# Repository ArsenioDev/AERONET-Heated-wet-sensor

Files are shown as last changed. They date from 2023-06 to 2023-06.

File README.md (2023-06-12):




# AERONET-Heated-wet-sensor

## Heated Wet Sensor for the NASA AERONET program

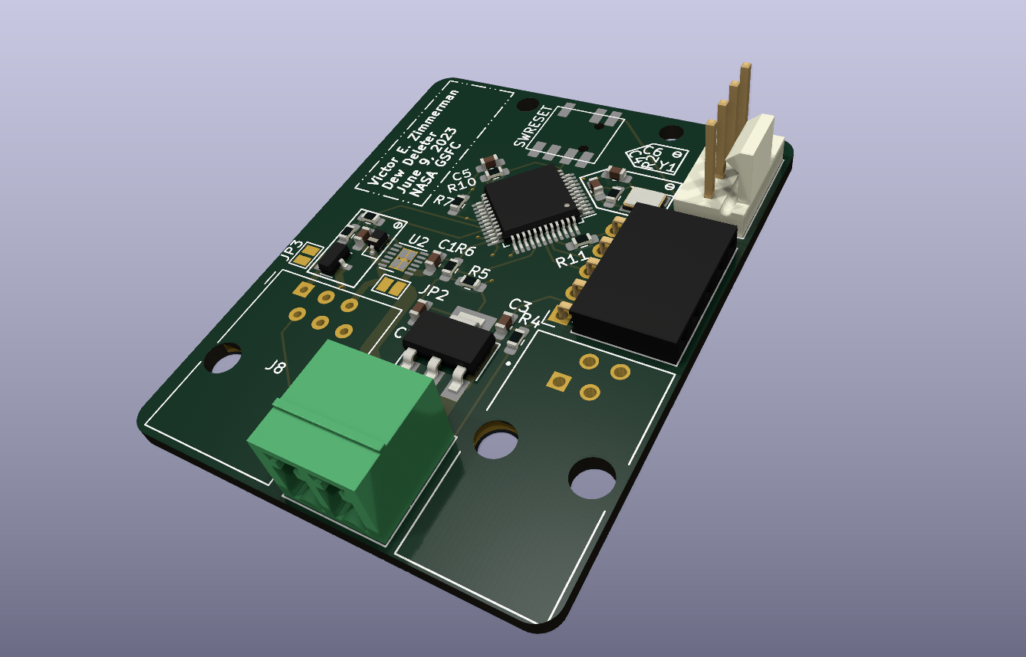
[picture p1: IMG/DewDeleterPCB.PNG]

Designed as part of USNA-to-NASA internship by Victor Zimmerman. 

### Description

A PCB designed to cure NASA AERONET robots suffering from dew induced crepuscular narcolepsy (instruments remaining in standby due to dew on wet sensor). The PCB is connected to temperature sensors, CIMEL control box and a heated wet sensor, in order to determine if the wet sensor is at risk of dew condensation. If so, turns on heater to prevent dew condensation. Determines dew risk by calculating dew point at BME280(atmospheric DP) and compares it to dew point calculated by temperature sensor underneath heated wet sensor(Sensor DP). Heats wet sensor until sensor DP is higher than atmospheric DP. Formula used to calculate dew point: 

𝐷𝑃=𝑇−(100 −𝐻)/5

Is mostly a "plug-and-play" design; does not need any programming or input from operator beyond initial code load. Runs on 12V and minimum 1.5A AC power supply (1.2A of which is for the heater, I_Lim set by load driver).

#### Initial code load prerequisites/software dependencies
* Arduino IDE with [STM32Duino](https://github.com/stm32duino/Arduino_Core_STM32) BSP core added
* Include libraries: [BolderFlight BME280](https://github.com/bolderflight/bme280), [OneWire](https://github.com/PaulStoffregen/OneWire), and [DallasTemperature](https://github.com/milesburton/Arduino-Temperature-Control-Library)
* SWD (Serial Wire Debug) upload mechanism from list of uploads. 
* Core selected **Generic STM32F103C6**

### Progress
- [x] Attempted to use RX8130
- [x] failed to use RX8130 :(
- [x] Succesfully pivoted to DS3121
- [x] realized RTC was unneccesary 
- [x] finished code
- [x] finished spahgetti point to point (with italian falg colored wires)
- [ ] ~~failed test in temperature chamber~~
- [x] ~~give up creating dew condensation after a PHD told us it would not work~~
- [x] Meanwhile, forced dew condensation in temperature chamber
- [x] Defined schematic of PCB with teensy stand in
- [x] replaced teensy with STM32F103
- [x] Finished schematic
- [x] routed PCB
- [x] Fine Tuned
- [x] Swagged out silkscreen
- [x] issued production order
- [x] finished progress list
- [ ] finished README and documentat...zzz

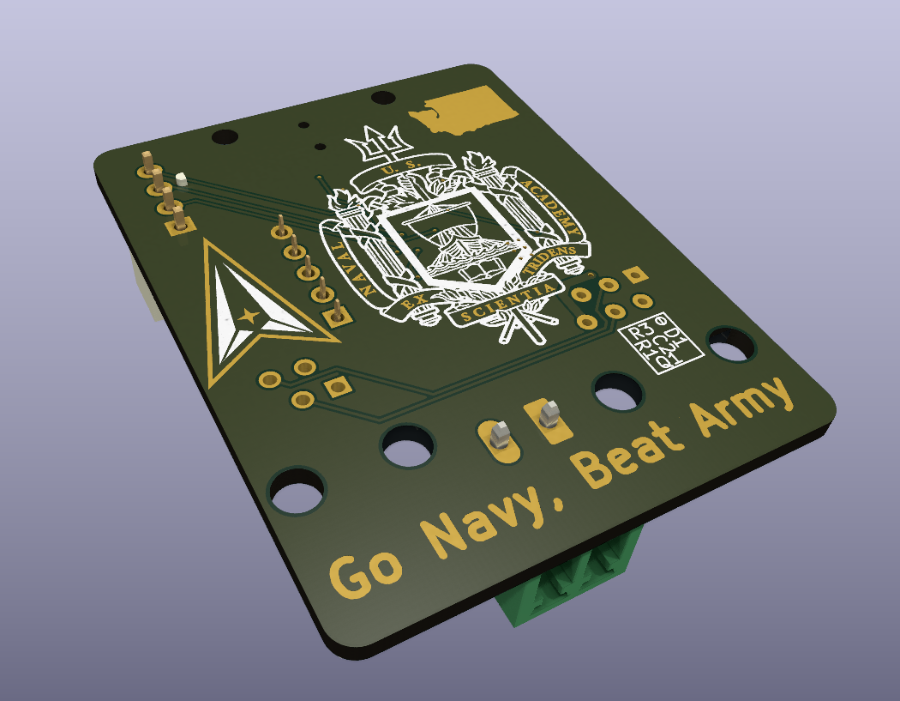
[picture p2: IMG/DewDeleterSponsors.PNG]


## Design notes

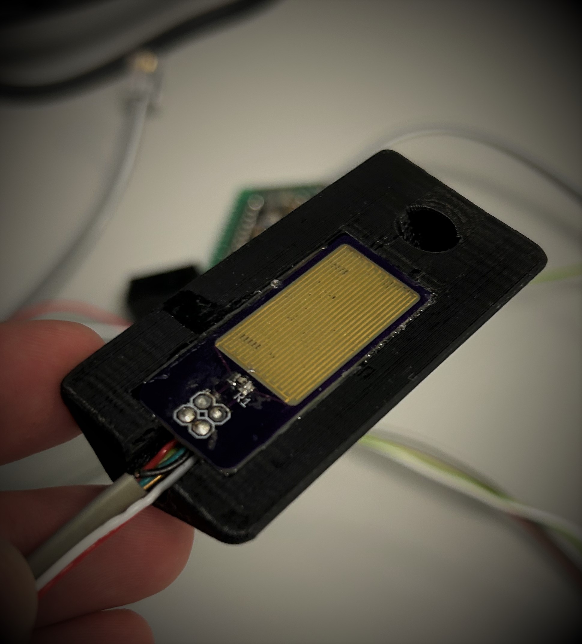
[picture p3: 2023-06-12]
IMG/IMG-4535_focused.jpg

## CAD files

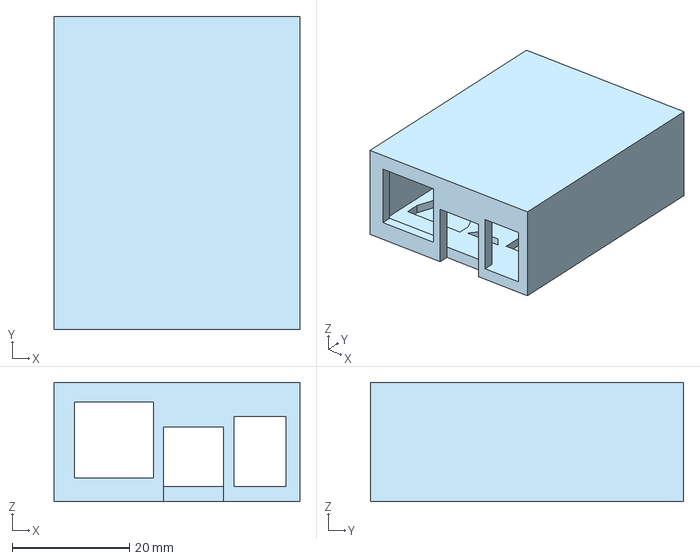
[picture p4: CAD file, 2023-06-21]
Hardware/Mechanical/Control unit holder.step
41.9 x 53.3 x 20.3 mm

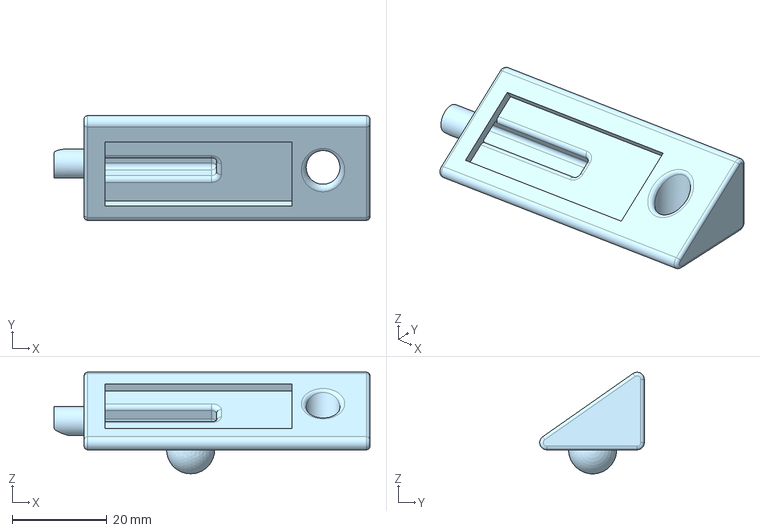
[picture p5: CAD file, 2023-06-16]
Hardware/Mechanical/Heated wet sensor holder.step
66.7 x 22.1 x 21.4 mm

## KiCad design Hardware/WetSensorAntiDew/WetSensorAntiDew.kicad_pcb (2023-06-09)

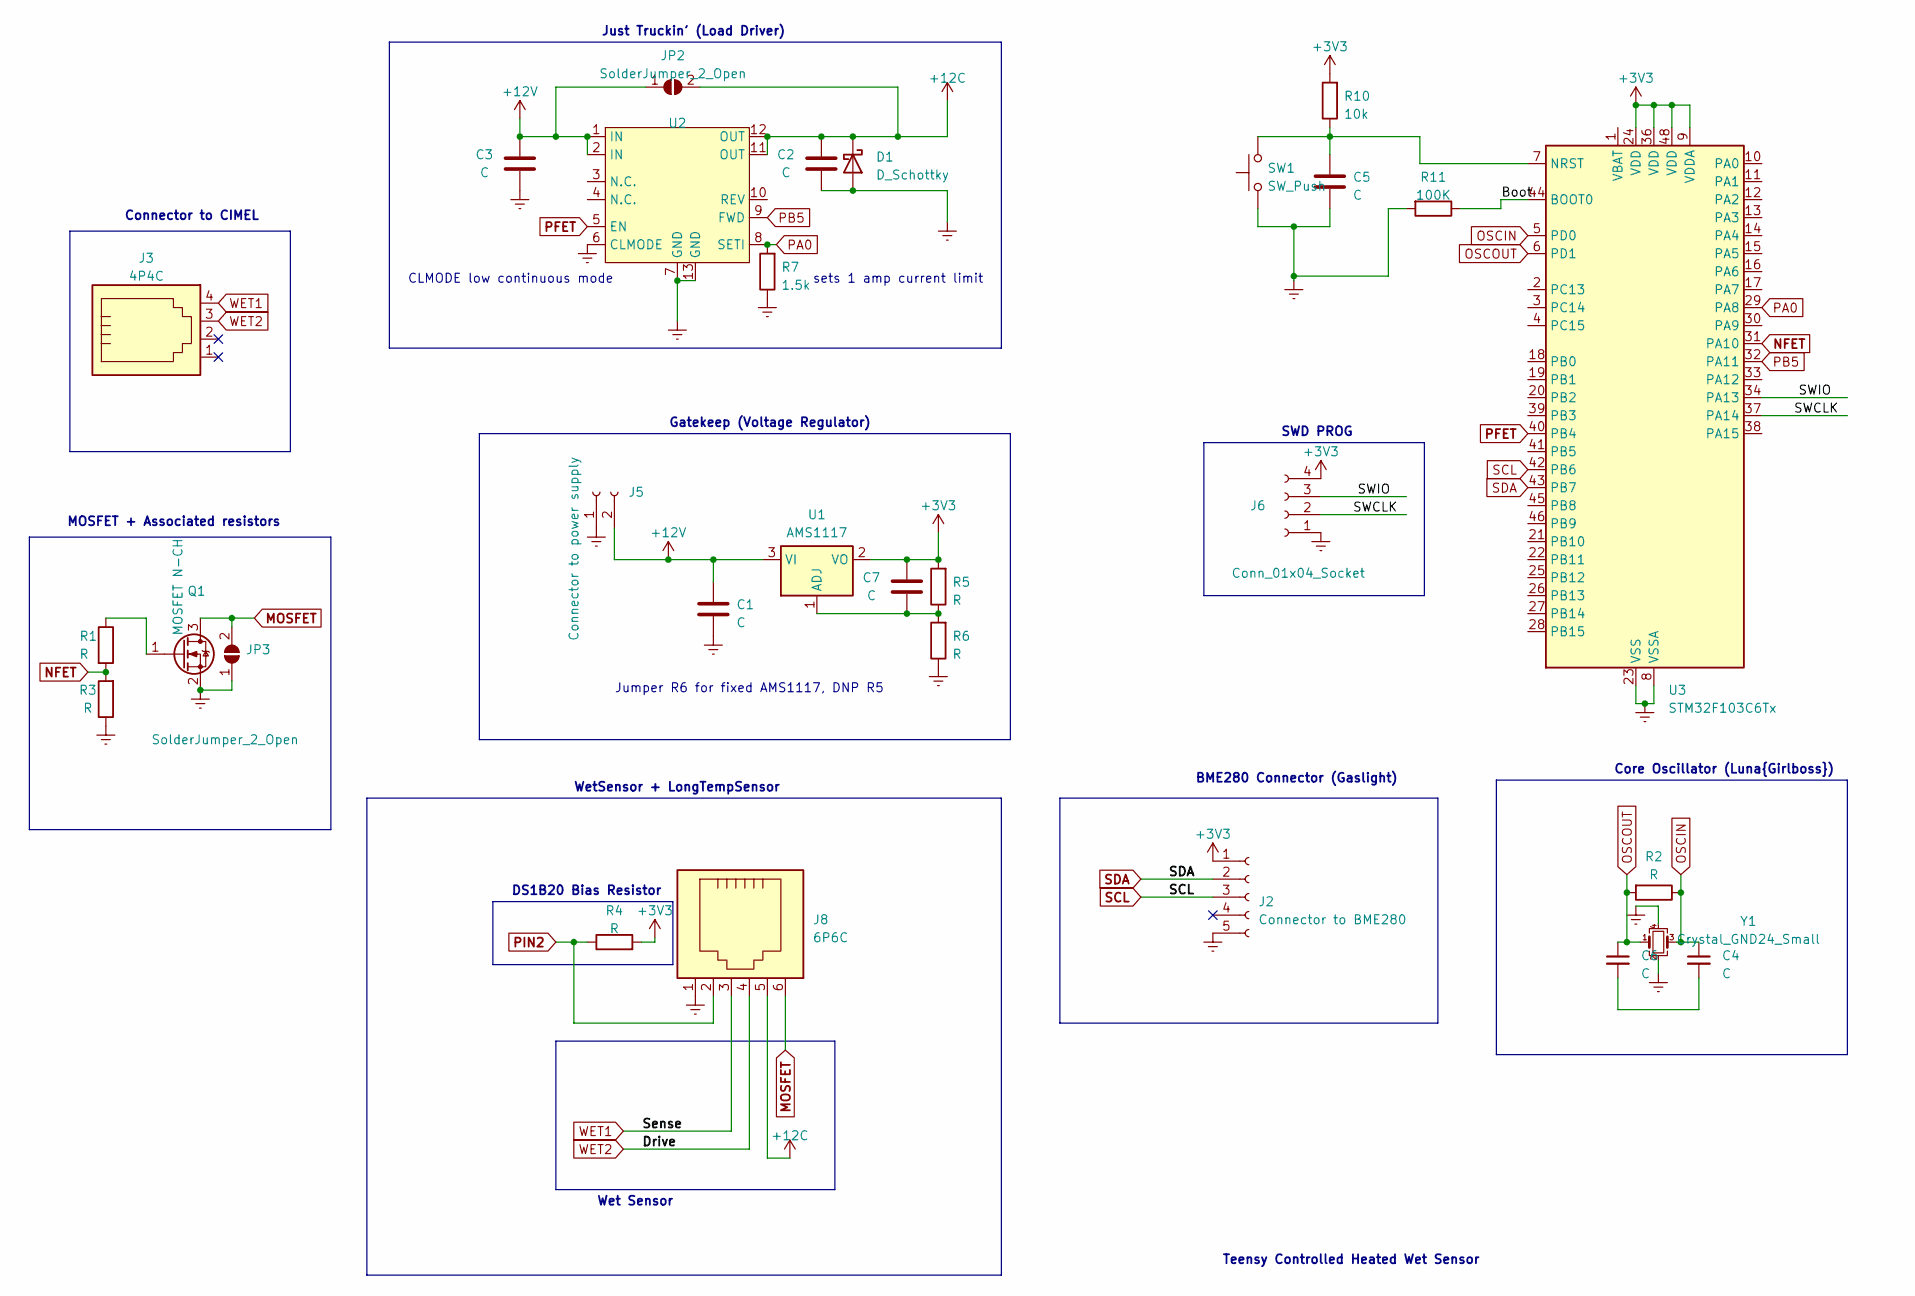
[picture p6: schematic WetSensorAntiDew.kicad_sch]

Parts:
C1, C2, C3, C4, C5, C6, C7: C; C_0603_1608Metric_Pad1.08x0.95mm_HandSolder
D1: D_Schottky; D_SOD-323
J2: Connector to BME280; PinSocket_1x05_P2.54mm_Horizontal
J3: 4P4C; BEL_SS-6444-NF
J5: Connector to power supply; PhoenixContact_MC_1,5_2-G-3.81_1x02_P3.81mm_Horizontal
J6: Conn_01x04_Socket; FanPinHeader_1x04_P2.54mm_Vertical
J8: 6P6C; RJ12_Amphenol_54601
JP2, JP3: SolderJumper_2_Open; SolderJumper-2_P1.3mm_Open_Pad1.0x1.5mm
Q1: MOSFET N-CH; SOT-23
R1, R2, R3, R4, R5, R6: R; R_0603_1608Metric_Pad0.98x0.95mm_HandSolder
R7: 1.5k; R_0603_1608Metric_Pad0.98x0.95mm_HandSolder
R10: 10k; R_0603_1608Metric_Pad0.98x0.95mm_HandSolder
R11: 100K; R_0603_1608Metric_Pad0.98x0.95mm_HandSolder
SW1: SW_Push; 228EJVAYFR
U1: AMS1117; SOT-223-3_TabPin2
U2: DFN-12-1EP_3x3mm_P0.5mm_EP1.6x2.5mm_ThermalVias
U3: STM32F103C6Tx; LQFP-48_7x7mm_P0.5mm
Y1: Crystal_GND24_Small; Crystal_SMD_3225-4Pin_3.2x2.5mm

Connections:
+3V3: C7.1, J2.1, J6.4, R4.2, R5.2, R10.2, U1.2 (VO), U3.9 (VDDA), U3.24 (VDD), U3.36 (VDD), U3.48 (VDD)
+12C: C2.1, D1.1 (K), J8.5, JP2.2 (B), U2.11 (OUT), U2.12 (OUT)
+12V: C1.1, C3.1, J5.2, JP2.1 (A), U1.3 (VI), U2.1 (IN), U2.2 (IN)
/Boot: R11.1, U3.44 (BOOT0)
/SWCLK: J6.2, U3.37 (PA14)
/SWIO: J6.3, U3.34 (PA13)
Earth: C1.2, C2.2, C3.2, C5.2, D1.2 (A), J2.5, J5.1, J6.1, J8.1, JP3.1 (A), Q1.2 (S), R3.1, R6.1, R7.1, R11.2, SW1.1, U2.6 (CLMODE), U2.7 (GND), U2.13 (GND), U3.8 (VSSA), U3.23 (VSS), U3.35 (VSS), U3.47 (VSS), Y1.2, Y1.4; also elsewhere on the board
MOSFET: J8.6, JP3.2 (B), Q1.3 (D)
NFET: R1.2, R3.2, U3.31 (PA10)
unnamed: C4.2, C6.2
unnamed: Q1.1 (G), R1.1
unnamed: C7.2, R5.1, R6.2, U1.1 (ADJ)
unnamed 12: C5.1, R10.1, SW1.2, U3.7 (NRST); also elsewhere on the board
OSCIN: C4.1, R2.1, U3.5 (PD0), Y1.3
OSCOUT: C6.1, R2.2, U3.6 (PD1), Y1.1
PA0: R7.2, U2.8 (SETI), U3.29 (PA8)
PB5: U2.9 (FWD), U3.32 (PA11)
PFET: U2.5 (EN), U3.40 (PB4)
PIN2: J8.2, R4.1
SCL: J2.3, U3.42 (PB6)
SDA: J2.2, U3.43 (PB7)
WET1: J3.4, J8.3
WET2: J3.3, J8.4

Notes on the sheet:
DS1B20 Bias Resistor
CLMODE low continuous mode
Wet Sensor
MOSFET + Associated resistors
BME280 Connector (Gaslight)
Jumper R6 for fixed AMS1117, DNP R5
Connector to CIMEL
WetSensor + LongTempSensor
Teensy Controlled Heated Wet Sensor
sets 1 amp current limit
Just Truckin' (Load Driver)
Core Oscillator (Luna{Girlboss})
Gatekeep (Voltage Regulator)
SWD PROG

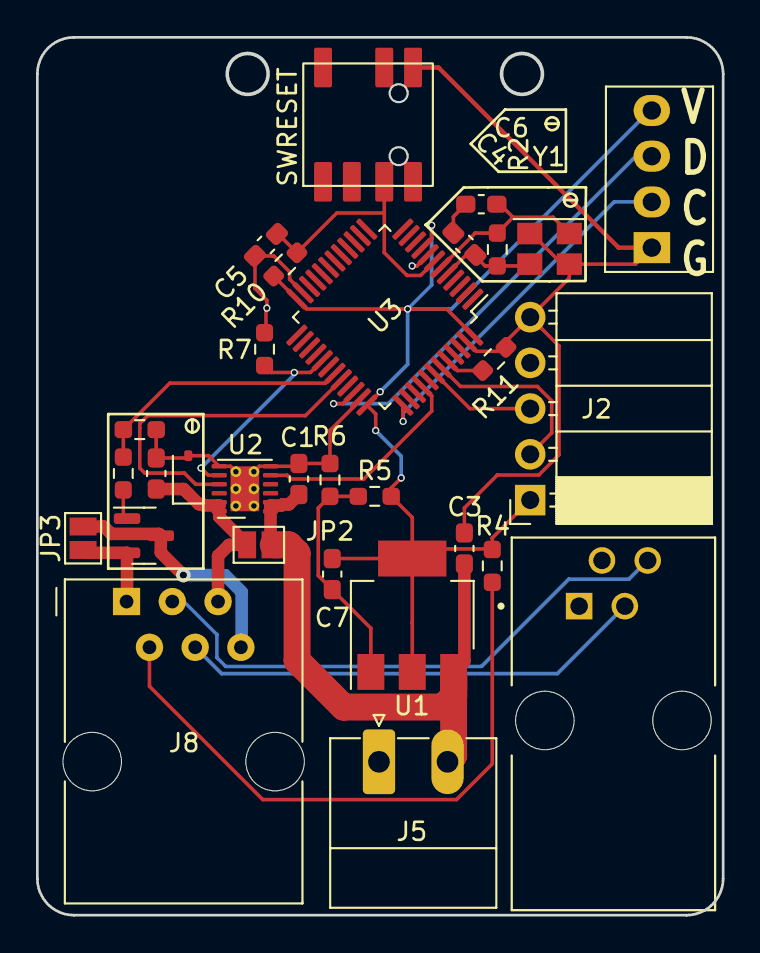
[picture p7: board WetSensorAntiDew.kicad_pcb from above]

Board: 2 copper layers, 38.1 x 48.8 mm, 30 parts (0 on the bottom side), 23 nets.

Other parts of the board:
SWRESET: SW_Push; 228EJVAYFR

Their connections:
Earth: SWRESET.1; also elsewhere on the board
unnamed 12: SWRESET.2; also elsewhere on the board

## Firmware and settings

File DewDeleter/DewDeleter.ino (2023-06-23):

/*
* Brian R Taylor
* brian.taylor@bolderflight.com
* 
* Copyright (c) 2021 Bolder Flight Systems Inc
*
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
* THE SOFTWARE IS PROVIDED “AS IS”, WITHOUT WARRANTY OF ANY KIND, EXPRESS OR
* IMPLIED, INCLUDING BUT NOT LIMITED TO THE WARRANTIES OF MERCHANTABILITY,
* FITNESS FOR A PARTICULAR PURPOSE AND NONINFRINGEMENT. IN NO EVENT SHALL THE
* AUTHORS OR COPYRIGHT HOLDERS BE LIABLE FOR ANY CLAIM, DAMAGES OR OTHER
* LIABILITY, WHETHER IN AN ACTION OF CONTRACT, TORT OR OTHERWISE, ARISING
* FROM, OUT OF OR IN CONNECTION WITH THE SOFTWARE OR THE USE OR OTHER DEALINGS
* IN THE SOFTWARE.
*/

#include "bme280.h"
#include <OneWire.h>
#include <DallasTemperature.h> 
//#include <DS3231.h>

/* BME-280 */
bfs::Bme280 bme;

OneWire oneWire(PB5); 
DallasTemperature sensors(&oneWire); 
//DS3231 myRTC;

// byte year;
// byte month;
// byte date;
// byte dOW;
// byte hour;
// byte minute;
// byte second;

// bool century = false;
// bool h12Flag;
// bool pmFlag;
// byte alarmDay, alarmHour, alarmMinute, alarmSecond, alarmBits;
// bool alarmDy, alarmH12Flag, alarmPmFlag;
// int counter = 10;

void setup() {
  /* Serial monitor for showing status and data */
  //Serial.begin(115200);
  sensors.begin(); 
  /* Initialize the I2C bus */
  Wire.begin();
  Wire.setClock(400000);
  /* Wire at the primary I2C s */
  pinMode(PB4, OUTPUT);
  bme.Config(&Wire, bfs::Bme280::I2C_ADDR_PRIM);// A8 and A7
  /* Initialize the BME-280 */
  if (!bme.Begin()) {
    //Serial.println("Error initializing communication with BME-280");
    //digitalWrite(PB4, HIGH);
    while (1) {}
  }



  

}

void loop() {
  //date setting function
  // char wantSet = Serial.read();
  // if (wantSet == 'x') {
  //   //Serial.println("1 fish");
  //   setDateStuff(year, month, date, dOW, hour, minute, second);
  // }

  
  DangerDew(AtmoSensorDew(), LongTempSensorDew());
  

  SerialPrinter(AtmoSensorDew(), LongTempSensorDew());

  // digitalWrite(0, myRTC.checkIfAlarm(1, true));
  // digitalWrite(1, myRTC.checkIfAlarm(2, true));

  delay(500);
}

//Unit Converters
//~~~~~~~~~~~~~~~~~~~~~~~~~~~~~~~~~~~~~~~~~~~~~~~~~~~~~~~~~~~~~~~~~~~~~~~~~
float FreedomUnits(float celcius){
  float freedom = (celcius * 1.8) + 32;
  return freedom; 
}

//Dew Point getters
//~~~~~~~~~~~~~~~~~~~~~~~~~~~~~~~~~~~~~~~~~~~~~~~~~~~~~~~~~~~~~~~~~~~~~~~~~~~~~~~~~~~~~~~~~~~~~~~~~~~~~~~~~~~~~~~~~

float LongTempSensorDew(){ 
  sensors.requestTemperatures(); 

  return (sensors.getTempCByIndex(0)-((100 - bme.humidity_rh())/5));
}

float AtmoSensorDew(){ 
  bme.Read();

  return bme.die_temp_c()-((100 - bme.humidity_rh())/5);
}

//~~~~~~~~~~~~~~~~~~~~~~~~~~~~~~~~~~~~~~~~~~~~~~~~~~~~~~~~~~~~~~~~~~~~~~~~~~~~~~~~~~~~~~~~~~~~~~~~~~~~~~~~~~~~~~~~~

boolean DangerDew(float AtmoDewPont, float SenseDewPont){

  boolean danger = AtmoDewPont + 10 > SenseDewPont;

  if (danger){
    digitalWrite(6, HIGH);
    digitalWrite(LED_BUILTIN, HIGH);
  } else {
    digitalWrite(6, LOW);
    digitalWrite(LED_BUILTIN,LOW);
  }

  return danger;
}

void SerialPrinter(float AtmoDewPont, float SenseDewPont){
  bme.Read();
  sensors.requestTemperatures(); 

  //Serial.print("Temp:");
  //Serial.print(bme.die_temp_c());
  // //Serial.print(", FreedomTemp:");
  // //Serial.print(FreedomUnits(bme.die_temp_c()));
  //Serial.print(", Humid:");
  //Serial.print(bme.humidity_rh());
  //Serial.print(", DewPont:");
  //Serial.print(AtmoDewPont);

  //Serial.print(", LongSenseC:"); 
  //Serial.print(sensors.getTempCByIndex(0));

  // //Serial.print(", LongSenseF:"); 
  // //Serial.print(sensors.getTempFByIndex(0)); 

  //Serial.print(", LongSenseDewPoint:");
  //Serial.print(SenseDewPont);

  //Serial.print(", ethernet reading:");
  //Serial.print(analogRead(21));

  // //Serial.print("   Time(YYMMDDwHHMMSS): 2");
	// if (century) {			// Won't need this for 89 years.
	// 	//Serial.print("1");
	// } else {
	// 	//Serial.print("0");
	// }
	// //Serial.print(myRTC.getYear(), DEC);
	// //Serial.print(' ');
	
	// // then the month
	// //Serial.print(myRTC.getMonth(century), DEC);
	// //Serial.print(" ");
  
	// // then the date
	// //Serial.print(myRTC.getDate(), DEC);
	// //Serial.print(" ");
  
	// // and the day of the week
	// //Serial.print(myRTC.getDoW(), DEC);
	// //Serial.print(" ");
  
	// // Finally the hour, minute, and second
	// //Serial.print(myRTC.getHour(h12Flag, pmFlag), DEC);
	// //Serial.print(" ");
	// //Serial.print(myRTC.getMinute(), DEC);
	// //Serial.print(" ");
	// //Serial.print(myRTC.getSecond(), DEC);

  // //Serial.print("   ");

  // //chack alarms
  // //Serial.print(myRTC.checkAlarmEnabled(1));
  // //Serial.print(" ");
  // //Serial.print(myRTC.checkAlarmEnabled(2));

  // //Serial.print("   ");
  // //Serial.print(myRTC.checkIfAlarm(1, false));
  // //Serial.print(" ");
  // //Serial.print(myRTC.checkIfAlarm(2, false));

  //Serial.println();

}

//Clock Functions
//~~~~~~~~~~~~~~~~~~~~~~~~~~~~~~~~~~~~~~~~~~~~~~~~~~~~~~~~~~~~~~~~~~~~~~~~~~~~~~~~~~~~~~~~~~~~~~~~~~~~~~~~~~~~~~~~~~

// void setDateStuff(byte& year, byte& month, byte& date, byte& dOW, byte& hour, byte& minute, byte& second) {
//   // Call this if you notice something coming in on
//   // the serial port. The stuff coming in should be in
//   // the order YYMMDDwHHMMSS, with an 'x' at the end.
//   boolean gotString = false;
//   char inChar;
//   byte temp1, temp2;
//   char inString[20];
  
//   //Serial.println("2 fish");

//   //byte j=0;
//   // while (!gotString) {
//   //   if (Serial.available()) {
//   //     //Serial.println("4 fish");
//   //     inChar = Serial.read();
//   //     inString[j] = inChar; //STUPID WHILE LOOP
//   //     j += 1;               //let this be a testament to while loop's inadequecy 
//   //     if (inChar == 'x') {
//   //       //Serial.println("5 fish");
//   //       gotString = true;
//   //     }
//   //   } 
//   // }

//   for(int i = 0; i < 13; i++){
//     inChar = Serial.read();
//     inString[i] = inChar;
//   }

//   //Serial.println(inString);
//   // Read year first
//   temp1 = (byte)inString[0] -48;
//   temp2 = (byte)inString[1] -48;
//   year = temp1*10 + temp2;
//   // now month
//   temp1 = (byte)inString[2] -48;
//   temp2 = (byte)inString[3] -48;
//   month = temp1*10 + temp2;
//   // now date
//   temp1 = (byte)inString[4] -48;
//   temp2 = (byte)inString[5] -48;
//   date = temp1*10 + temp2;
//   // now Day of Week
//   dOW = (byte)inString[6] - 48;
//   // now hour
//   temp1 = (byte)inString[7] -48;
//   temp2 = (byte)inString[8] -48;
//   hour = temp1*10 + temp2;
//   // now minute
//   temp1 = (byte)inString[9] -48;
//   temp2 = (byte)inString[10] -48;
//   minute = temp1*10 + temp2;
//   // now second
//   temp1 = (byte)inString[11] -48;
//   temp2 = (byte)inString[12] -48;
//   second = temp1*10 + temp2;

//   myRTC.setClockMode(false);  // set to 24h
//   //setClockMode(true); // set to 12h
      
//   myRTC.setYear(year);
//   myRTC.setMonth(month);
//   myRTC.setDate(date);
//   myRTC.setDoW(dOW);
//   myRTC.setHour(hour);
//   myRTC.setMinute(minute);
//   myRTC.setSecond(second);
  
//   // Test of alarm functions
//   // set A1 to one minute past the time we just set the clock
//   // on current day of week.


//   myRTC.setA1Time(dOW, hour, minute + 1, second, 00001000 /*sets alarm to match hour, minutes and seconds*/, true, false, false);
  
//   // set A2 to two minutes past, on current day of month.
//   myRTC.setA2Time(date, hour, minute + 3, 00001000 /*sets alarm to match hour, minutes and seconds*/, false, false, false);
//   // Turn on both alarms, with external interrupt
//   myRTC.turnOnAlarm(1);
//   myRTC.turnOnAlarm(2);
      
// }

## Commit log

2023-06-07 initial board setup
    [WetSensorAntiDew.kicad_pcb, WetSensorAntiDew.kicad_sch]
2023-06-07 First schematic of HeatedWetSensorPCB
    [WetSensorAntiDew.kicad_sch]
2023-06-07 Added Gatekeep
    [WetSensorAntiDew.kicad_sch]
2023-06-07 added connector to gatekeep for power supply
    [WetSensorAntiDew.kicad_sch]
2023-06-07 added footprints and properly spaced teensy connectors
    [WetSensorAntiDew.kicad_pcb, WetSensorAntiDew.kicad_sch]
2023-06-07 finished Pcb layout
    [WetSensorAntiDew.kicad_pcb, WetSensorAntiDew.kicad_sch]
2023-06-07 end of day commit on JUN 7
    [WetSensorAntiDew.kicad_sch]
2023-06-08 WIP new voltage regulator
    [WetSensorAntiDew.kicad_pcb]
2023-06-08 add file for footprint of 4p4c
2023-06-08 added custom stm32 core
    [WetSensorAntiDew.kicad_sch]
2023-06-08 Updates to board
    [WetSensorAntiDew.kicad_pcb, WetSensorAntiDew.kicad_sch]
2023-06-08 More progress
    [WetSensorAntiDew.kicad_pcb, WetSensorAntiDew.kicad_sch]
2023-06-09 Final* PCB design
    [WetSensorAntiDew.kicad_pcb]
2023-06-09 small edits to DRC Check pass
    [WetSensorAntiDew.kicad_pcb]
2023-06-09 edited switch and programming pins connections
    [WetSensorAntiDew.kicad_pcb]
2023-06-09 added USNA logo
    [WetSensorAntiDew.kicad_pcb]
2023-06-09 shrunk anchors aweigh
    [WetSensorAntiDew.kicad_pcb]
2023-06-09 USNA emblem tweaks
    [WetSensorAntiDew.kicad_pcb]
2023-06-09 Added Semper Supra :)
    [WetSensorAntiDew.kicad_pcb]
2023-06-09 Finalized silkscreen
    [WetSensorAntiDew.kicad_pcb]
2023-06-09 Tuned pinouts, corrected N/P switches
    [WetSensorAntiDew.kicad_pcb, WetSensorAntiDew.kicad_sch]
2023-06-09 Reset silk, corrected prog header
    [WetSensorAntiDew.kicad_pcb]
2023-06-09 Final design review pre-fab tuning
    [WetSensorAntiDew.kicad_pcb, WetSensorAntiDew.kicad_sch]
2023-06-15 Updated readme and added images of holder prototyping
    [Heated wet sensor holder.step]
2023-06-16 updated heated wet sensor holder to include nubbin for heat shrink
    [Heated wet sensor holder.step]
2023-06-16 shortened sensor holder
    [Heated wet sensor holder.step]
2023-06-21 added a 3D printed box for pcb
    [Control unit holder.step]
2023-06-23 Closeout updates to bring to parity with PCB
